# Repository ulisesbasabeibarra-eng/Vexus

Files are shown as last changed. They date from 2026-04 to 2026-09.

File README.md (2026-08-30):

# Triatlon-2026
Robot Triatlón para Bonaerenses 2026 por parte de los Alumnos de 6° año. **Campeones Región 2**

- [@Ulises Basabe](https://github.com/ulisesbasabeibarra-eng)
- [@Facundo Dominguez](https://github.com/facundodominguez1)
- [@Ramiro Trejo](https://github.com/RamiiTrejo)

## Componentes 

1-Esp32 38 pines

1-Bateria 2s de 450mAh

1-Bateria 3s de 1050mAh

2-Driver de motores BTS7960

2-Motores Titán de 1000RPM

## Sensores
1-Regleta **QTR8a** [Datasheet]()

3-Sensores infrarrojos **TCRT5000** [Datasheet]()

5-Sensores **Sharp Gp2y0a02yk0f**: [Datasheet]()

-3 frontales

-2 laterales

## PCB

Este PCB fue realizado con el software de diseño libre y gratuito KiCad, el cual nos facilita el uso debido a su interfaz intuitiva 

En este se implemento el diseño doble faz y componentes SMD (como lo son capacitores, una resitencia y un regulador)





## Modelo 3D

En este proyecto se utilizo Autodesk, plataforma de software, ademas de ser muy utilizado a la hora de hacer diseños 3D, gracias a que este ofrece una amplia gama de software como AutoCAD, Fusion 360, Inventor y 3ds Max, utilizados en sectores como la ingeniería, la arquitectura, el entretenimiento y el diseño de productos.

(https://postimg.cc/xcYmVDSj)

(https://postimg.cc/kB1QmJF6)

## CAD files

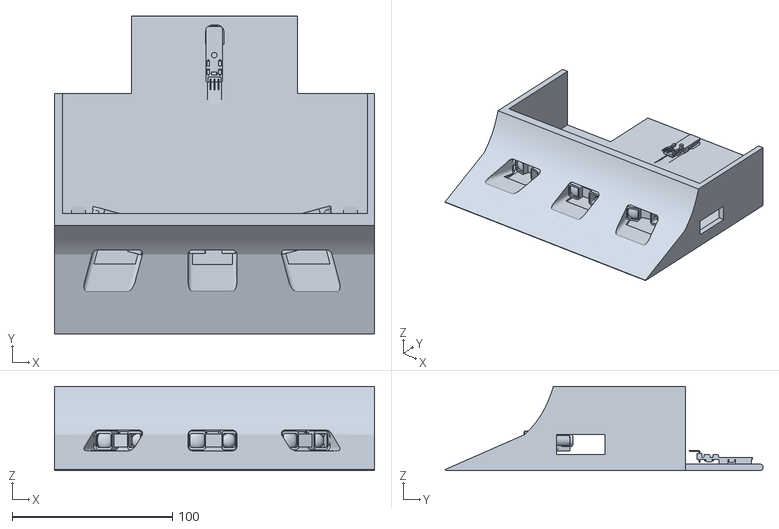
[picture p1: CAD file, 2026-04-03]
Carroceria/Vexus_V2/Revisión_1/Vexus V.2.stl
200.0 x 198.7 x 52.7

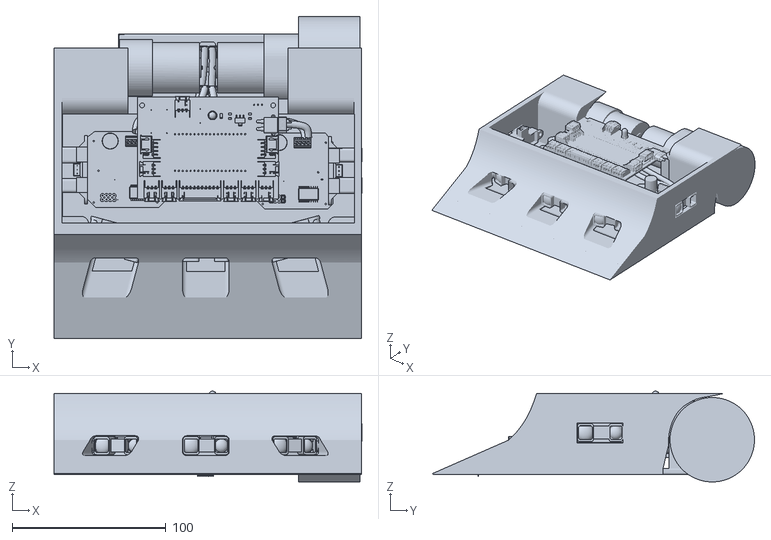
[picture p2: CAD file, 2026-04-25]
Carroceria/Vexus_V2/Revisión_2/Vexus v.3.stl
200.3 x 209.7 x 59.2

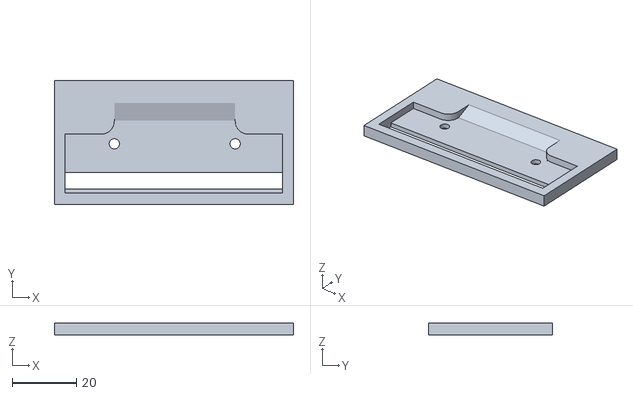
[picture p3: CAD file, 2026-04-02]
En desarrollo/Pruebas/Qtr (modelo regleta).stl
74.1 x 38.4 x 3.87

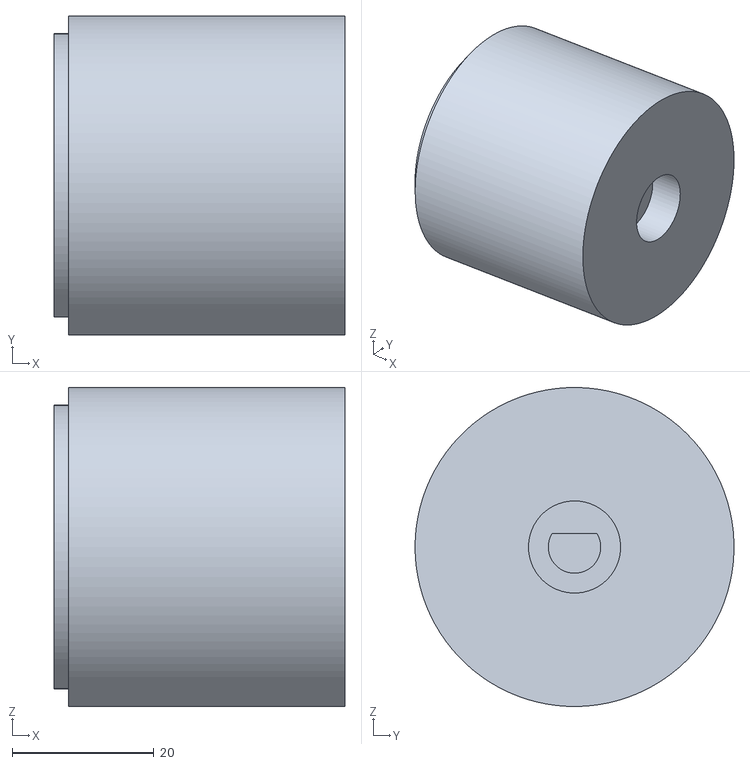
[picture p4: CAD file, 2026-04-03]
En desarrollo/Ruedas/Ruedas Vexus V.1.stl
41.0 x 45.0 x 45.0

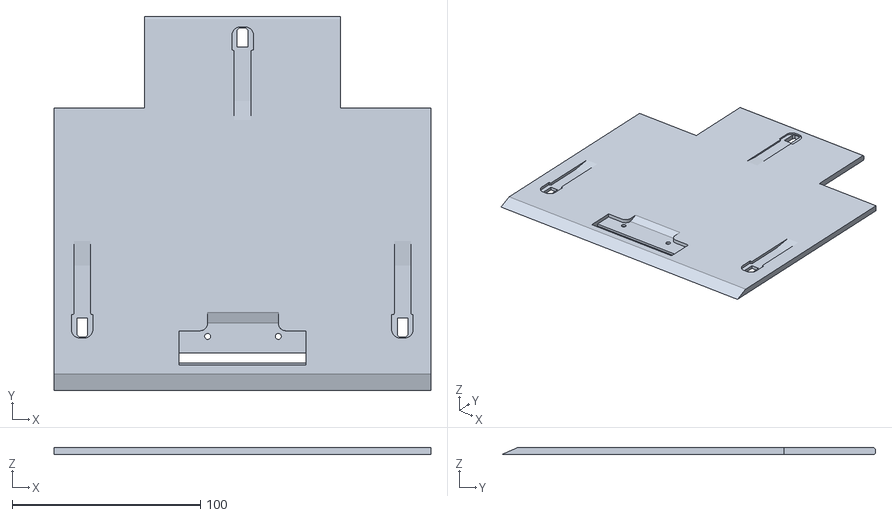
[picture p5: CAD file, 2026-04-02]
En desarrollo/Vexus.stl
200.0 x 198.5 x 3.87

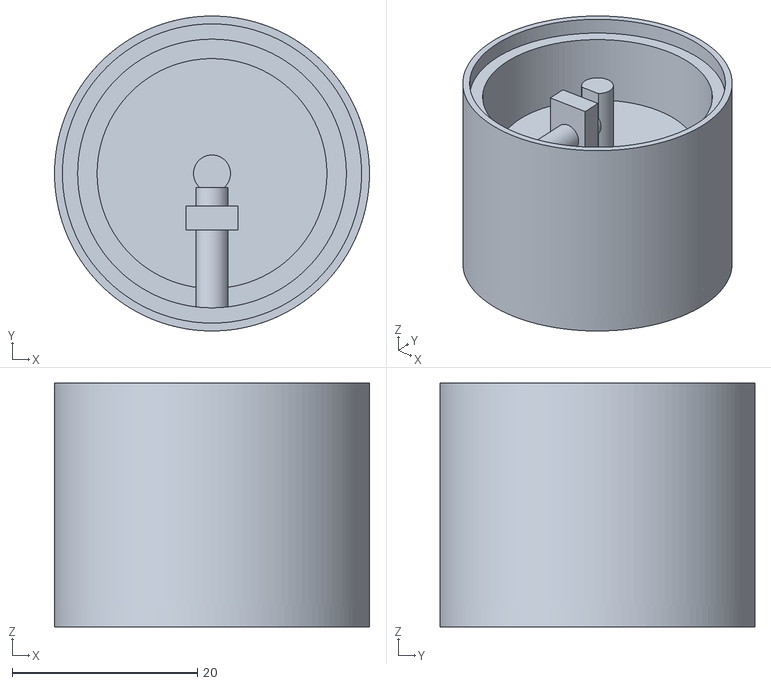
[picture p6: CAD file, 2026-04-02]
En desarrollo/Ruedas/Rueda_JGA.stl
34.0 x 34.0 x 26.3

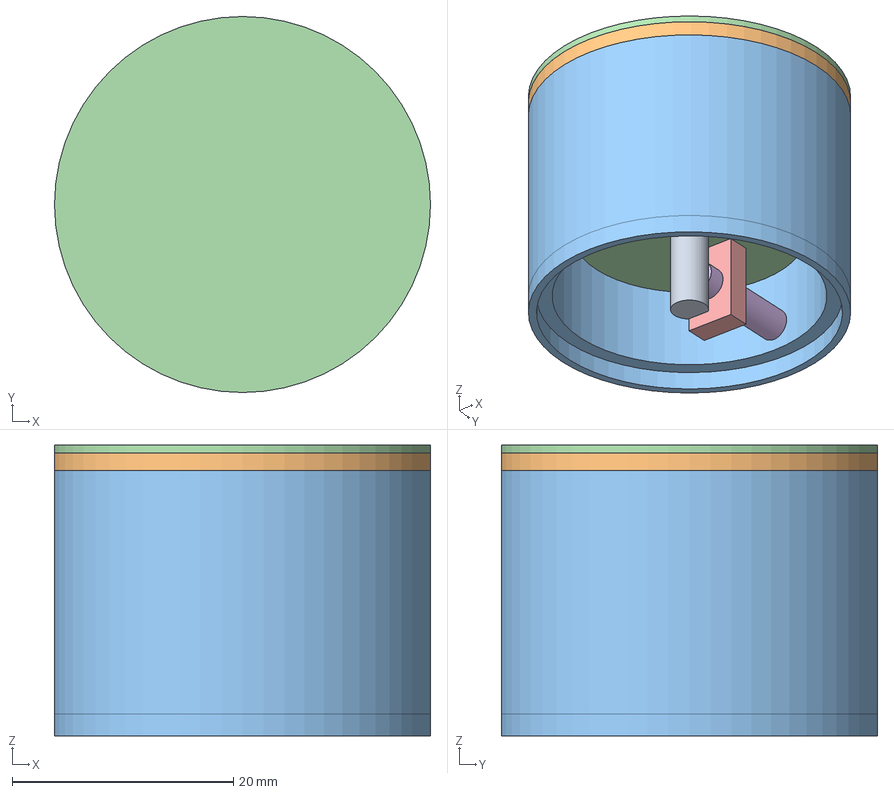
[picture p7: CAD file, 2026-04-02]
En desarrollo/Ruedas/Rueda_JGA25-370 v2.step
34.0 x 34.0 x 26.3 mm

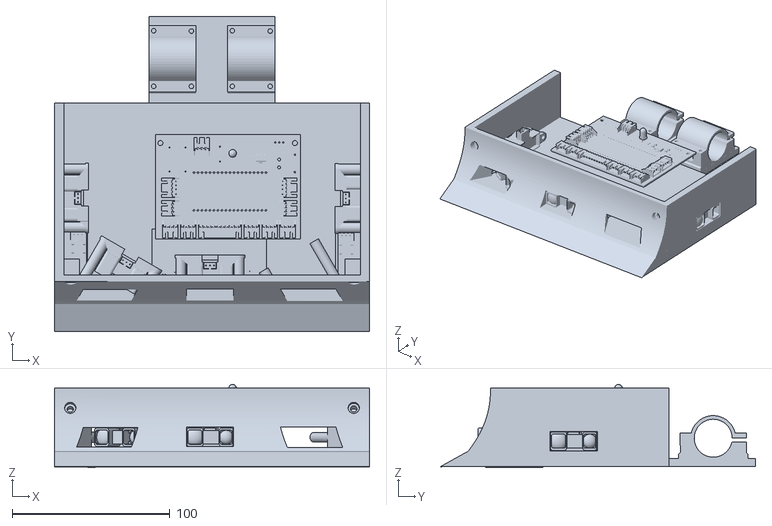
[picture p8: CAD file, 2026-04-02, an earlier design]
Carroceria/Vexus-V1/Vexus version 1.stl
200.0 x 200.0 x 52.9

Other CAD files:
Carroceria/Vexus-V1/Vexus V.1.f3z
Carroceria/Vexus_V2/Revisión_1/Vexus V.2.f3z
Carroceria/Vexus_V2/Revisión_2/Vexus v.3.f3z
En desarrollo/Ruedas/Ruedas Vexus V.1.f3d
En desarrollo/Vexus.f3z

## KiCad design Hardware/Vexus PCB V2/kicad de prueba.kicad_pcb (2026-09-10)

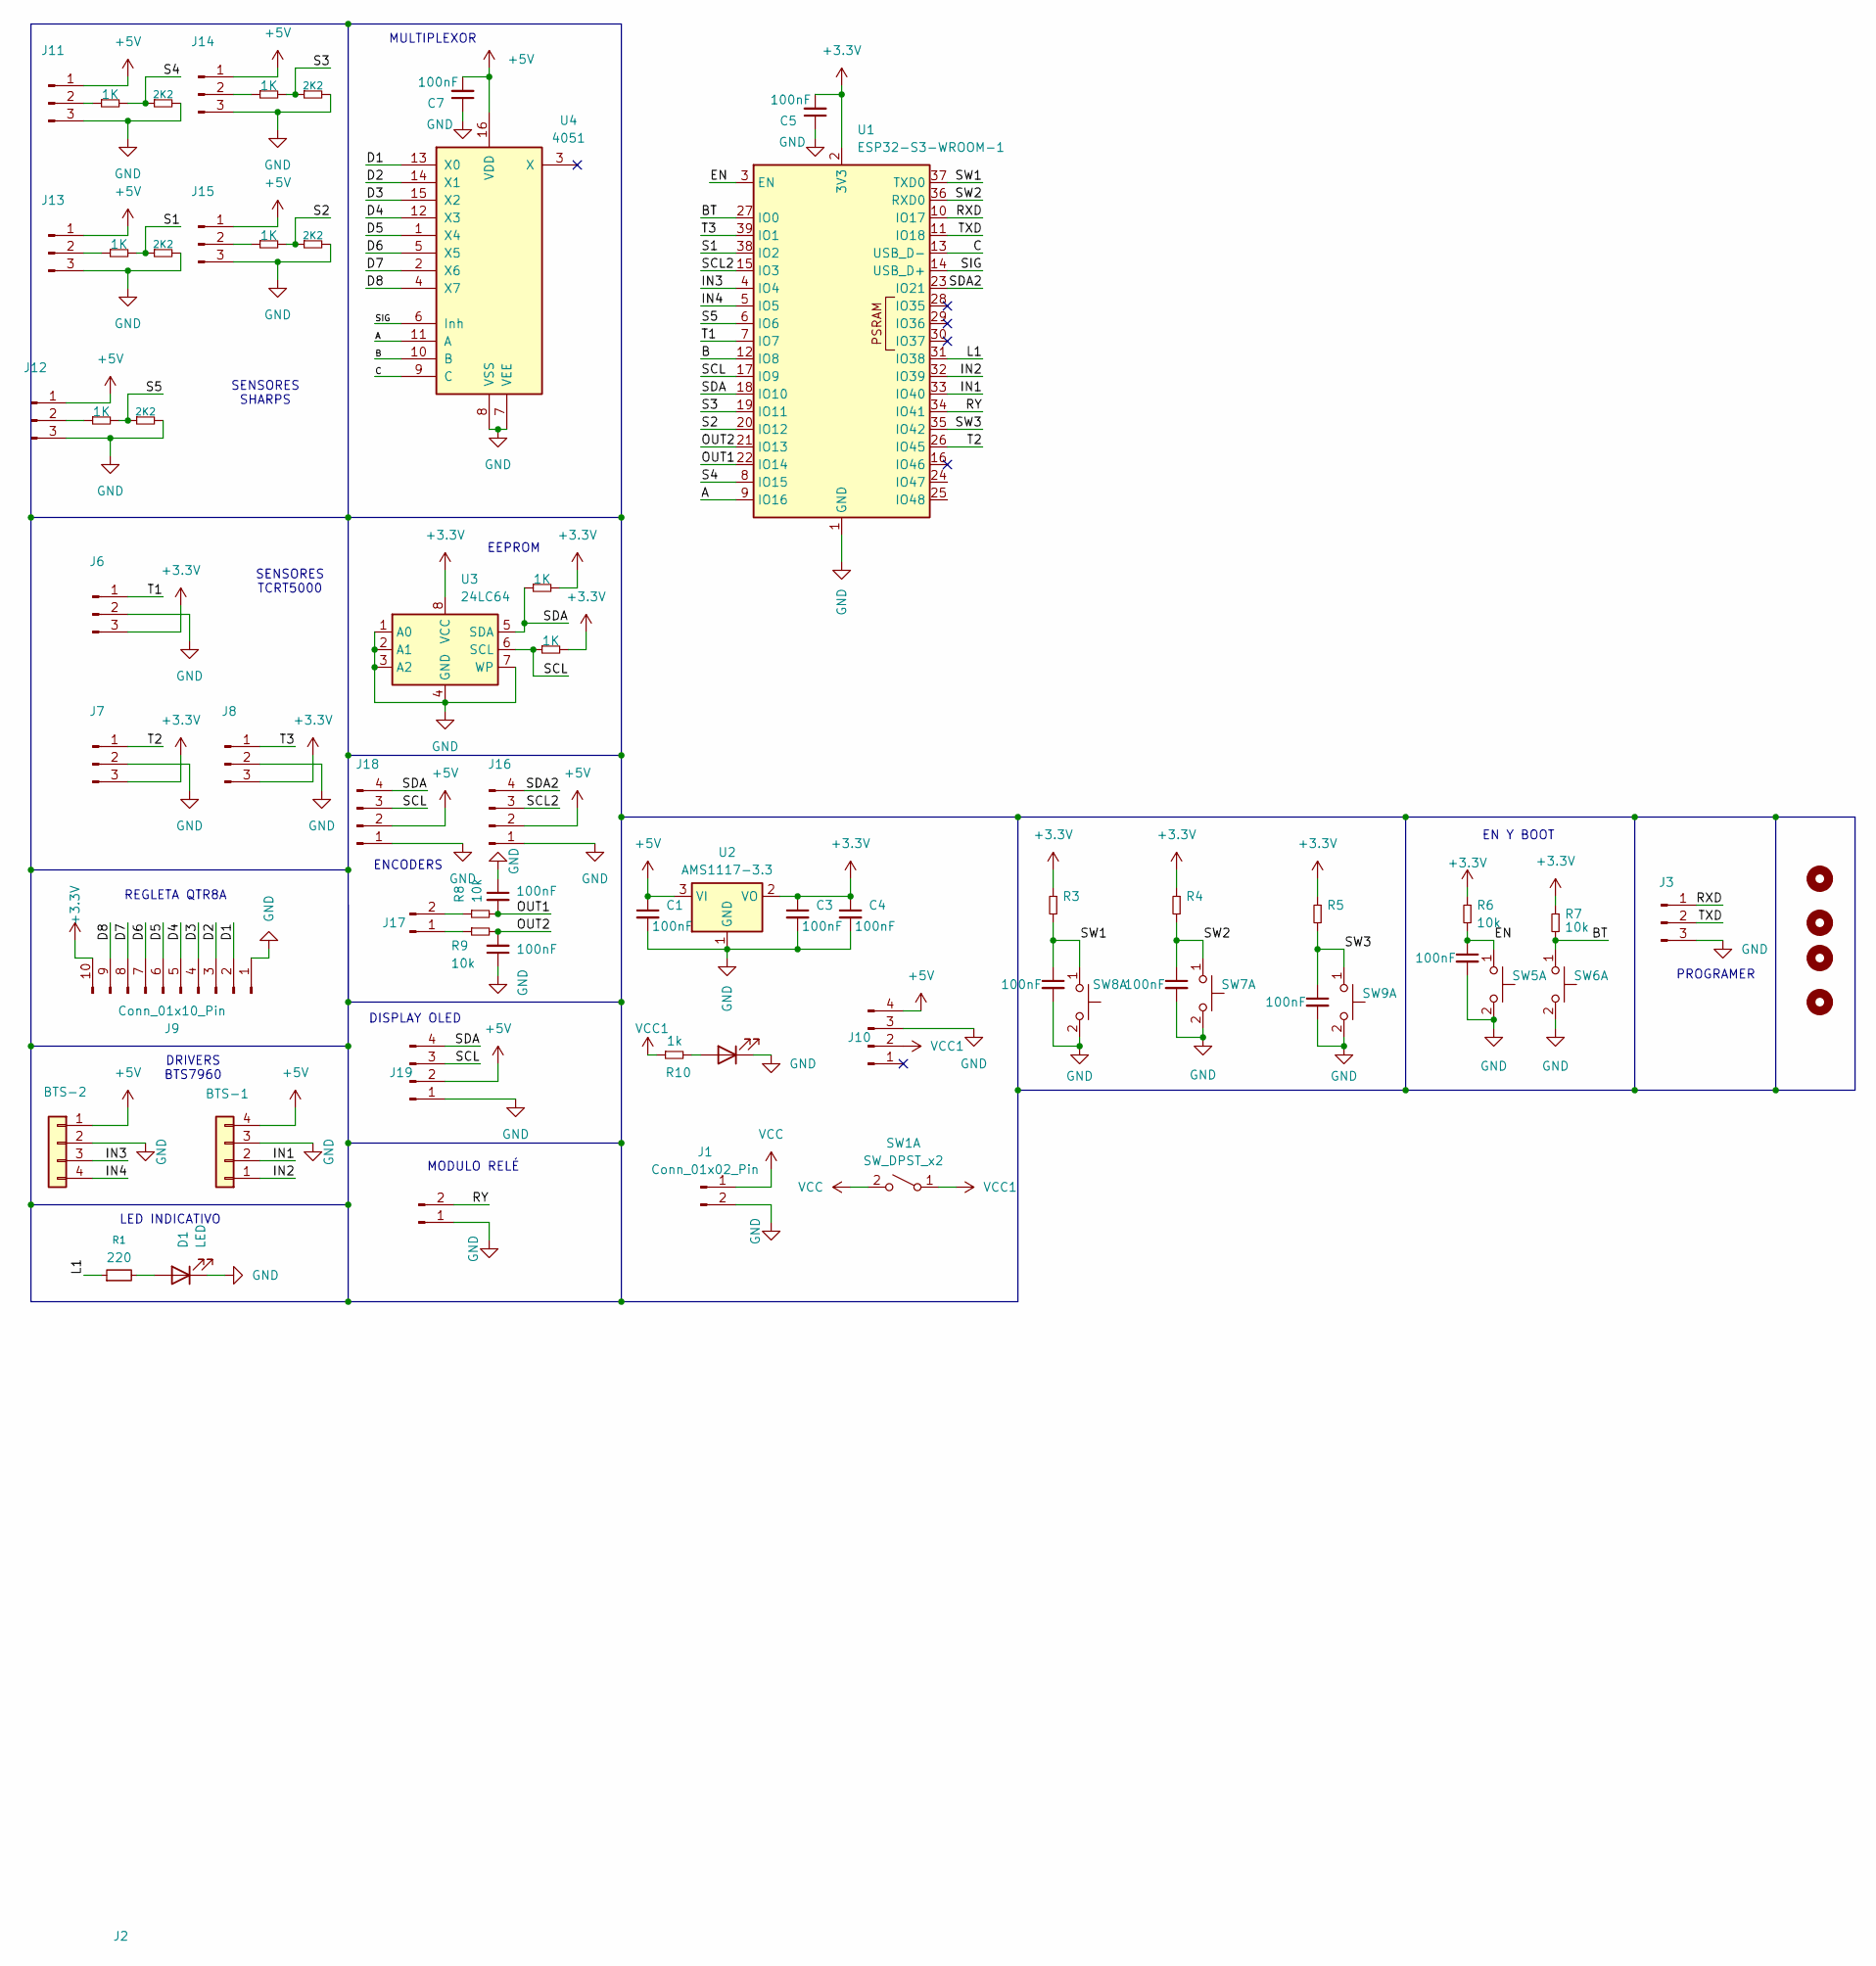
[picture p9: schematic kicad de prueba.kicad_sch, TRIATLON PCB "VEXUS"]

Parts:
C1, C3, C4, C5, C6, C7, C8, C9, C10, C11, C12: 100nF; C_0805_2012Metric_Pad1.18x1.45mm_HandSolder
D1, D2: LED; LED_0805_2012Metric_Pad1.15x1.40mm_HandSolder
H1, H2, H3, H4: MountingHole; MountingHole_3.2mm_M3_ISO7380
J1: Conn_01x02_Pin; AMASS_XT30PW-M_1x02_P2.50mm_Horizontal
J2: Conn_01x02_Pin; JST_XH_S2B-XH-A_1x02_P2.50mm_Horizontal
J3: Conn_01x03_Pin; PinHeader_1x03_P2.54mm_Vertical
J4: BTS-1; JST_XH_S4B-XH-A-1_1x04_P2.50mm_Horizontal
J5: BTS-2; JST_XH_S4B-XH-A-1_1x04_P2.50mm_Horizontal
J6, J7, J8, J11, J12, J13, J14, J15: Conn_01x03_Pin; JST_XH_S3B-XH-A-1_1x03_P2.50mm_Horizontal
J9: Conn_01x10_Pin; JST_XH_S10B-XH-A_1x10_P2.50mm_Horizontal
J10: Conn_01x04_Pin; Step_Down_Mini
J16, J18, J19: Conn_01x04_Pin; JST_XH_B4B-XH-A_1x04_P2.50mm_Vertical
J17: Conn_01x02_Pin; JST_XH_B2B-XH-A_1x02_P2.50mm_Vertical
R1: 220; R_0805_2012Metric_Pad1.20x1.40mm_HandSolder
R3, R4, R5, R6, R7, R8, R9: 10k; R_0805_2012Metric_Pad1.20x1.40mm_HandSolder
R10: 1k; R_0805_2012Metric_Pad1.20x1.40mm_HandSolder
R15, R16, R19, R21, R23, R25, R26: 1K; R_0805_2012Metric_Pad1.20x1.40mm_HandSolder
R17, R18, R20, R22, R24: 2K2; R_0805_2012Metric_Pad1.20x1.40mm_HandSolder
SW1: SW_DPST_x2; Switch Slide
SW5, SW6, SW7, SW8, SW9: SW_Push_Dual_x2; SW SMD 3.5X6X5
U1: ESP32-S3-WROOM-1
U2: AMS1117-3.3; SOT-223-3_TabPin2
U3: 24LC64; DIP-8_W7.62mm_LongPads
U4: 4051; SOIC-16_4.55x10.3mm_P1.27mm

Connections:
+3.3V: C3.1, C4.1, C5.2, J6.3, J7.3, J8.3, J9.10, R3.1, R4.1, R5.1, R6.1, R7.1, R25.2, R26.2, U1.2 (3V3), U2.2 (VO), U3.8 (VCC)
+5V: C1.1, C7.2, J4.4, J5.1, J10.4, J11.1, J12.1, J13.1, J14.1, J15.1, J16.2, J18.2, J19.2, U2.3 (VI), U4.16 (VDD)
/A: U1.9 (IO16), U4.11 (A)
/B: U1.12 (IO8), U4.10 (B)
/BT: R7.2, SW6.1 (C), U1.27 (IO0)
/C: U1.13 (USB_D-), U4.9 (C)
/D1: J9.2, U4.13 (X0)
/D2: J9.3, U4.14 (X1)
/D3: J9.4, U4.15 (X2)
/D4: J9.5, U4.12 (X3)
/D5: J9.6, U4.1 (X4)
/D6: J9.7, U4.5 (X5)
/D7: J9.8, U4.2 (X6)
/D8: J9.9, U4.4 (X7)
/EN: C6.1, R6.2, SW5.1 (C), U1.3 (EN)
/IN1: J4.2, U1.33 (IO40)
/IN2: J4.1, U1.32 (IO39)
/IN3: J5.3, U1.4 (IO4)
/IN4: J5.4, U1.5 (IO5)
/L1: R1.1, U1.31 (IO38)
/OUT1: C11.2, R8.2, U1.22 (IO14)
/OUT2: C12.2, R9.2, U1.21 (IO13)
/RXD: J3.1, U1.10 (IO17)
/RY: J2.2, U1.34 (IO41)
/S1: R23.2, R24.1, U1.38 (IO2)
/S2: R16.2, R18.1, U1.20 (IO12)
/S3: R19.2, R20.1, U1.19 (IO11)
/S4: R21.2, R22.1, U1.8 (IO15)
/S5: R15.2, R17.1, U1.6 (IO6)
/SCL: J18.3, J19.3, R26.1, U1.17 (IO9), U3.6 (SCL)
/SCL2: J16.3, U1.15 (IO3)
/SDA: J18.4, J19.4, R25.1, U1.18 (IO10), U3.5 (SDA)
/SDA2: J16.4, U1.23 (IO21)
/SIG: U1.14 (USB_D+), U4.6 (Inh)
/SW1: C10.1, R3.2, SW8.1 (C), U1.37 (TXD0)
/SW2: C9.1, R4.2, SW7.1 (C), U1.36 (RXD0)
/SW3: C8.1, R5.2, SW9.1 (C), U1.35 (IO42)
/T1: J6.1, U1.7 (IO7)
/T2: J7.1, U1.26 (IO45)
/T3: J8.1, U1.39 (IO1)
/TXD: J3.2, U1.11 (IO18)
GND: C1.2, C3.2, C4.2, C5.1, C6.2, C7.1, C8.2, C9.2, C10.2, C11.1, C12.1, D1.1 (K), D2.1 (K), J1.2, J2.1, J3.3, J4.3, J5.2, J6.2, J7.2, J8.2, J9.1, J10.3, J11.3, J12.3, J13.3, J14.3, J15.3, J16.1, J18.1, J19.1, R17.2, R18.2, R20.2, R22.2, R24.2, SW5.2 (D), SW6.2 (D), SW7.2 (D), SW8.2 (D), SW9.2 (D), U1.1 (GND), U1.40 (GND), U1.41 (GND), U2.1 (GND), U3.1 (A0), U3.2 (A1), U3.3 (A2), U3.4 (GND), U3.7 (WP), U4.7 (VEE), U4.8 (VSS)
unnamed: D1.2 (A), R1.2
unnamed: D2.2 (A), R10.2
unnamed: J11.2, R21.1
unnamed: J12.2, R15.1
unnamed: J13.2, R23.1
unnamed: J14.2, R19.1
unnamed: J15.2, R16.1
unnamed: J17.1, R9.1
unnamed: J17.2, R8.1
VCC: J1.1, SW1.2 (B)
VCC1: J10.2, R10.1, SW1.1 (A)

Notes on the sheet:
EEPROM
REGLETA QTR8A
SENSORES TCRT5000
DRIVERS BTS7960
LED INDICATIVO
PROGRAMER
SENSORES SHARPS
DISPLAY OLED
ENCODERS
MODULO RELÉ
MULTIPLEXOR
EN Y BOOT

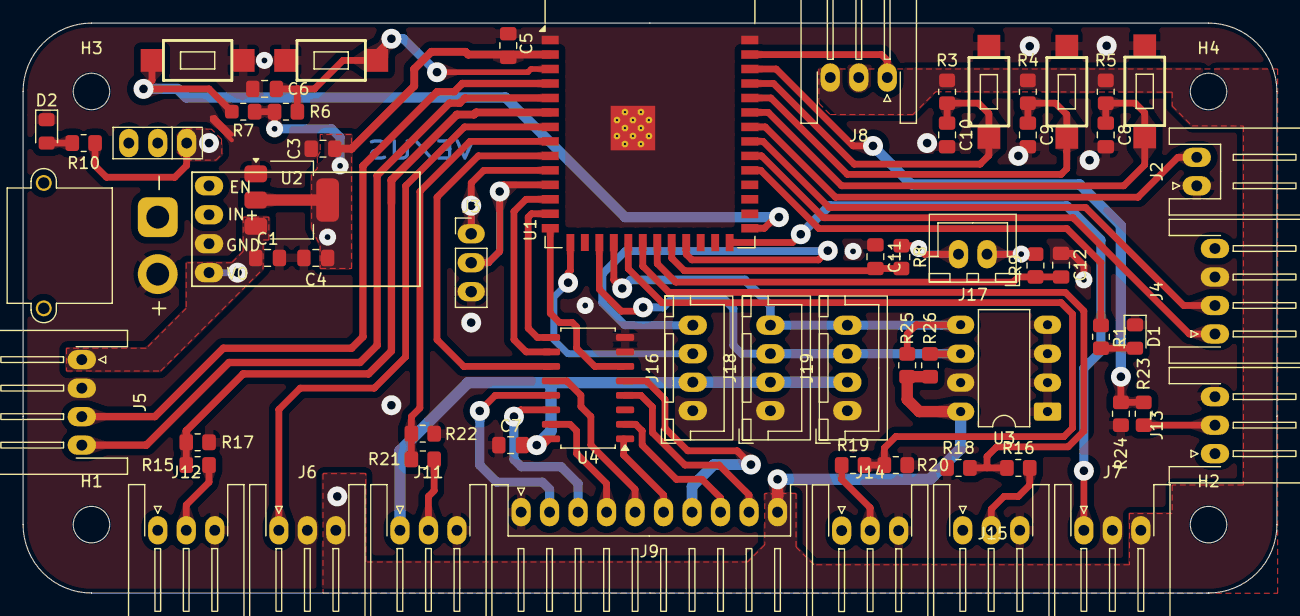
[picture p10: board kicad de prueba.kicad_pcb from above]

Board: 2 copper layers, 110.0 x 50.0 mm, 67 parts (0 on the bottom side), 53 nets.

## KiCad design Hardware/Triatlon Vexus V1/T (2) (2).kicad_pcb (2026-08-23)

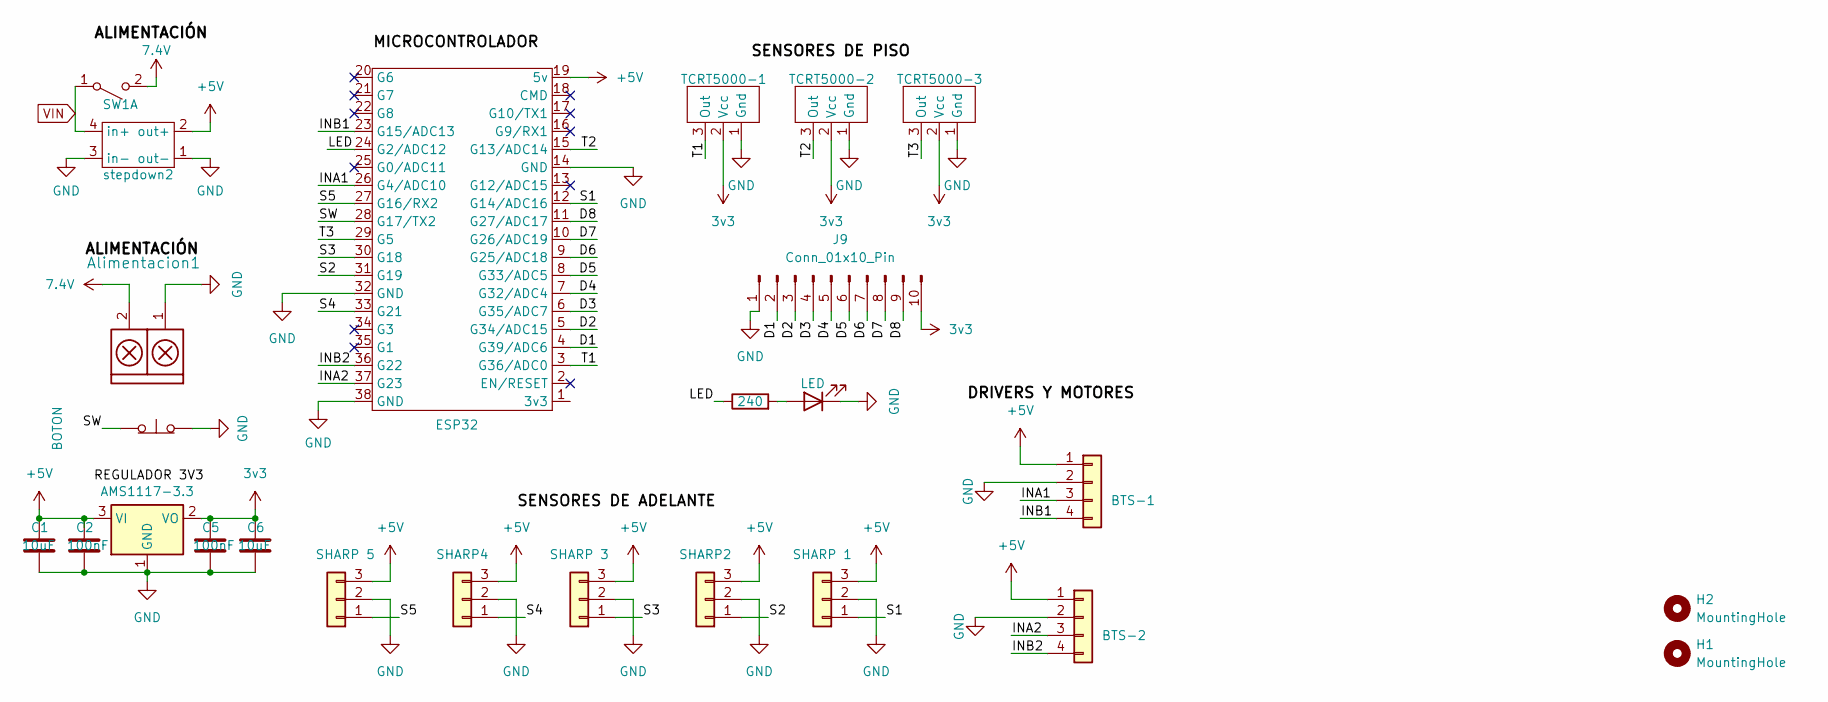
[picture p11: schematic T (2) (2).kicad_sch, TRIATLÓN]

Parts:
Alimentacion1: TB_1X2; AMASS_XT30PW-M_1x02_P2.50mm_Horizontal
C1, C6: 10uF; C_0805_2012Metric
C2, C5: 100nF; C_0805_2012Metric
D1: LED; LED_D5.0mm
ESP32: esp32 38 pin usb-c
H1, H2: MountingHole; MountingHole_3.2mm_M3_DIN965
J1: SHARP 1; JST_XH_S3B-XH-A-1_1x03_P2.50mm_Horizontal
J2: BTS-1; JST_XH_S4B-XH-A_1x04_P2.50mm_Horizontal
J3: SHARP2; JST_XH_S3B-XH-A-1_1x03_P2.50mm_Horizontal
J4: SHARP 3; JST_XH_S3B-XH-A-1_1x03_P2.50mm_Horizontal
J5: BTS-2; JST_XH_S4B-XH-A_1x04_P2.50mm_Horizontal
J7: SHARP 5; JST_XH_S3B-XH-A-1_1x03_P2.50mm_Horizontal
J8: SHARP4; JST_XH_S3B-XH-A-1_1x03_P2.50mm_Horizontal
J9: Conn_01x10_Pin; JST_XH_S10B-XH-A-1_1x10_P2.50mm_Horizontal
R1: 240; R_1206_3216Metric_Pad1.30x1.75mm_HandSolder
SW1: SW_DPST_x2; switch smd
SW2: BOTON; Button
TCRT5000-1, TCRT5000-2, TCRT5000-3: JST_XH_S3B-XH-A-1_1x03_P2.50mm_Horizontal
U2: AMS1117-3.3; SOT-223-3_TabPin2
stepdown2: STEPDOWN

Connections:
3v3: C5.1, C6.1, J9.10, TCRT5000-1.2 (Vcc), TCRT5000-2.2 (Vcc), TCRT5000-3.2 (Vcc), U2.2 (VO)
7.4V: Alimentacion1.2, SW1.2 (B)
+5V: C1.1, C2.1, ESP32.19 (5v), J1.3, J2.1, J3.3, J4.3, J5.1, J7.3, J8.3, U2.3 (VI), stepdown2.2 (out+)
/D1: ESP32.4 (G39/ADC6), J9.2
/D2: ESP32.5 (G34/ADC15), J9.3
/D3: ESP32.6 (G35/ADC7), J9.4
/D4: ESP32.7 (G32/ADC4), J9.5
/D5: ESP32.8 (G33/ADC5), J9.6
/D6: ESP32.9 (G25/ADC18), J9.7
/D7: ESP32.10 (G26/ADC19), J9.8
/D8: ESP32.11 (G27/ADC17), J9.9
/INA1: ESP32.26 (G4/ADC10), J2.3
/INA2: ESP32.37 (G23), J5.3
/INB1: ESP32.23 (G15/ADC13), J2.4
/INB2: ESP32.36 (G22), J5.4
/LED: ESP32.24 (G2/ADC12), R1.1
/S1: ESP32.12 (G14/ADC16), J1.1
/S2: ESP32.31 (G19), J3.1
/S3: ESP32.30 (G18), J4.1
/S4: ESP32.33 (G21), J8.1
/S5: ESP32.27 (G16/RX2), J7.1
/SW: ESP32.28 (G17/TX2), SW2.1 (A)
/T1: ESP32.3 (G36/ADC0), TCRT5000-1.3 (Out)
/T2: ESP32.15 (G13/ADC14), TCRT5000-2.3 (Out)
/T3: ESP32.29 (G5), TCRT5000-3.3 (Out)
GND: Alimentacion1.1, C1.2, C2.2, C5.2, C6.2, D1.1 (K), ESP32.14 (GND), ESP32.32 (GND), ESP32.38 (GND), J1.2, J2.2, J3.2, J4.2, J5.2, J7.2, J8.2, J9.1, SW2.2 (B), TCRT5000-1.1 (Gnd), TCRT5000-2.1 (Gnd), TCRT5000-3.1 (Gnd), U2.1 (GND), stepdown2.1 (out-), stepdown2.3 (in-)
unnamed: D1.2 (A), R1.2
VIN: SW1.1 (A), stepdown2.4 (in+)

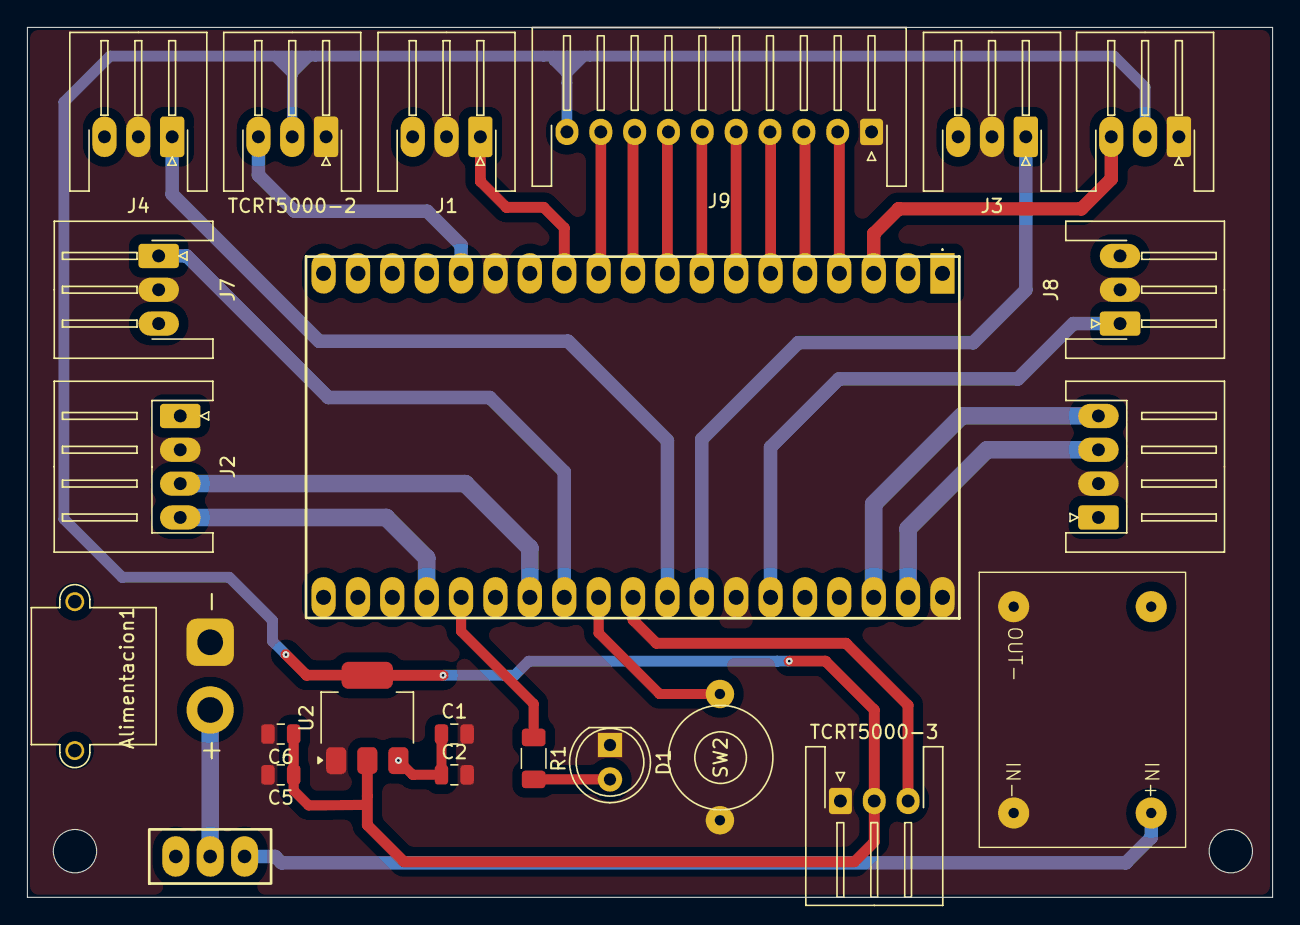
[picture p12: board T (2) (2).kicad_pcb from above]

Board: 2 copper layers, 92.0 x 64.3 mm, 25 parts (0 on the bottom side), 28 nets.

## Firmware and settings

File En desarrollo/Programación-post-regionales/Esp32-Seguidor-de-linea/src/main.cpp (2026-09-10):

#include <Arduino.h>
#include <Wire.h>
#include <Adafruit_GFX.h>
#include <Adafruit_SSD1306.h>

#include "Oled.h"
#include "Motores.h"
#include "Encoders.h"

Oled pantallita;
Motores motorcitos(4, 5, 40, 39);// IN1A, IN1B, IN2A, IN2B
Encoders myencoder;

#define boton1 43 //up - subir- derecha
#define boton2 44 //enter - calibrar 
#define boton3 42 //down - bajar - izquierda
#define led 38

#define TIME_PID 3

#define sig 3
#define pinA 16
#define pinB 19
#define pinC 20

#define eeprom_direccion 0x50

#define as5600_direccion 0x36

enum Estado {
  pantallazo,
  menu_principal,
  iniciar_carrera,
  comenzar, //es para que arranque el velocista
  calibracion,
  val_select,
  val_edit,
  EXTRA
};
Estado estadoActual = pantallazo;

// Variables de tiempo para Splash Screen
unsigned long tiempopantallazo = 0;

// Variables del Menú Principal
const int num_items = 6;
String menuItems[num_items] = {"Comenzar", "Calibracion", "Guardar Cal", "Cargar Cal", "Valores", "Extra"};
int menuIndex = 0;

// para el submenú de valores
int valorIndex = 0; 

// time cronómetro
unsigned long tiempoInicio = 0;
bool cronoActivo = false;

int Sensor[8] = {39,34,35,32,33,25,26,27}; // falta aclarar tema del multi

int umbrales[8] = {0,0,0,0,0,0,0,0};
bool estado_booleano[8] = {0,0,0,0,0,0,0,0};
uint8_t channel[8] = {4,5,6,7,8,9,10,11};

// === VARIABLES PID Y CONTROL ===
int pos = 0;
int poslast = 350;
float kp = 0.32; //aumenta la fuerza con la que el robot corrige el error, si se aumenta demasiado oscila
float ki = 0;
float kd = 6.45; //suavizante de la oscilación
float error = 0, error2 = 0, error3 = 0, error4 = 0, error5 = 0, error6 = 0;
float lastError = 0;
float integral = 0;
float derivative = 0;
float setpoint = 400;
int correccion = 0;
int max_rpm = 1000;
int baseSpeed = 370; //medido en rpm 5 de pwm en 255 equivale a 2 rpm aprox
bool anterior = 1; 

unsigned long lastTimePID = 0;

int PWM1 = baseSpeed;  //pwm de la izquierda
int PWM2 = baseSpeed;  //pwm de la derecha

int calcularPID(int lectura) {
    error = setpoint - lectura;
    integral = error + error2 + error3 + error4 + error5 + error6;
    derivative = error - lastError;
    lastError = error;
    
    error6 = error5;
    error5 = error4;
    error4 = error3;
    error3 = error2;
    error2 = error;
    
    return (kp * error + ki * integral + kd * derivative);
}
//------- ENCODERS -------
int calcularPWM(float rpmDeseada, float rpmReal, int pwmBase){
  float KP= 0.05;
  float Error = rpmDeseada - rpmReal;
  float Correccion = Error * KP;
  int pwmFinal = pwmBase + Correccion;

return constrain(pwmFinal, 0, 4095);
}
//-------MULTIPLEXOR-------

void leermulti2(){
  for(int i= 0; i<8; i++){
    digitalWrite(pinA, i&0x01);
    digitalWrite(pinB, i&0x02);
    digitalWrite(pinC, i&0x04);
    Sensor[i]=analogRead(sig);
  }
}

//-------FIN MULTIPLEXOR-------

void calibrar(){
    int blancos[8] = {0,0,0,0,0,0,0,0};
    int negro[8] = {0,0,0,0,0,0,0,0};
    digitalWrite(led, 1);
    while(digitalRead(boton2) == 1) { delay(1); }
    
    leermulti2();
    for (int x = 0; x < 8; x++) {
        blancos[x] = Sensor[x];    
    delay(100);
    }

    while(digitalRead(boton2) == 0) { delay(1); }
    digitalWrite(led, 0);
    delay(500);
    digitalWrite(led, 1);
    
    while(digitalRead(boton2)) { delay(1); }
    
    leermulti2();
    for (int x = 0; x < 8; x++) {
        negro[x] = Sensor[x];
    }
    for(int x = 0; x < 8; x++){
        umbrales[x] = (blancos[x] + negro[x]) / 2;
    }
    digitalWrite(led, 0);
    delay(1000);
    digitalWrite(led, 1);

    while(digitalRead(boton2) == 1) { delay(1); }
}

void sprint(){

  leermulti2();
  for(int x = 0; x < 8; x++){
    estado_booleano[x] =Sensor[x] > umbrales[x]? 0 : 1;
  }
  
  if(estado_booleano[0] == 0 && estado_booleano[0] != estado_booleano[7]){
    for(int x = 0; x < 8; x++){
      pos += 100 * estado_booleano[x];
    }
    anterior = 1;
  }
  if(estado_booleano[7] == 0 && estado_booleano[0] != estado_booleano[7]){
    for(int x = 0; x < 8; x++){
      pos += 100 * !estado_booleano[x];
    }
    anterior = 0;
  }
  if(estado_booleano[0] == estado_booleano[7]){
    if(anterior){
      for(int x = 0; x < 8; x++){
        pos += 100 * estado_booleano[x];
      }
    }
    else{
      for(int x = 0; x < 8; x++){
        pos += 100 * !estado_booleano[x];
      }
    }
  }
  
  if(micros() - lastTimePID >= TIME_PID){
      correccion = calcularPID(pos);
      lastTimePID = micros();
      
      int velocidadIzquierda = constrain (baseSpeed - correccion, 0, max_rpm);
      int velocidadDerecha  = constrain (baseSpeed + correccion, 0, max_rpm);

      int pwmBaseIzq = map(velocidadIzquierda, 0, max_rpm, 0, 4095);
      int pwmBaseDer = map(velocidadDerecha, 0, max_rpm, 0, 4095);

      float rpmRealIzq = myencoder.calculoRPM1();
      float rpmRealDer = myencoder.calculoRPM2();

      int pwmFinalIzquierda = calcularPWM(velocidadIzquierda, rpmRealIzq, pwmBaseIzq);
      int pwmFinalDerecha  = calcularPWM(velocidadDerecha, rpmRealDer, pwmBaseDer);

      motorcitos.moverMotores(pwmFinalIzquierda, pwmFinalDerecha);
  }

  pos = 0;
}

//-------OLED-------
void manejarValoresSelect(bool up, bool enter, bool down) {
  if (up) { 
    valorIndex--;
    if (valorIndex < 0) valorIndex = 3;
  }
  if (down) {
    valorIndex++;
    if (valorIndex > 3) valorIndex = 0;
  }
  if (enter) {
    if (valorIndex == 3) {
      estadoActual = menu_principal; 
    } else {
      estadoActual = val_edit;   //puede ir en vez de val_edit menu_principal
    }
  }
}

void ejecutarAccionMenu() {
  switch (menuIndex) {
      case 0: // Cronometro
      estadoActual = iniciar_carrera;
      break;
    case 1: // calibracion
      pantallita.mostrarMensaje("Calibrando...");
      calibrar();
      pantallita.mostrarMensaje("Calibracion OK");
      delay(1000);
      break;
    case 2: // guarda Calibracion
      pantallita.mostrarMensaje("Guardando...");
      {
        byte* datos = (byte*)umbrales; // Convertimos el arreglo de enteros a bytes
        for(unsigned int i = 0; i < sizeof(umbrales); i++) {
          Wire.beginTransmission(eeprom_direccion);
          Wire.write((i >> 8) & 0xFF);   // Parte alta de la dirección de memoria
          Wire.write(i & 0xFF);          // Parte baja de la dirección de memoria
          Wire.write(datos[i]);          // Dato a guardar
          Wire.endTransmission();
          delay(5); // Tiempo de escritura obligatorio del datasheet
        }
      }
      pantallita.mostrarMensaje("Cal Guardada!");
      delay(1500);
      break;
    case 3: // carga Calibracion
      pantallita.mostrarMensaje("Cargando...");
      {
        byte* datos = (byte*)umbrales;
        for(unsigned int i = 0; i < sizeof(umbrales); i++) {
          Wire.beginTransmission(eeprom_direccion);
          Wire.write((i >> 8) & 0xFF);
          Wire.write(i & 0xFF);
          Wire.endTransmission();
          
          Wire.requestFrom(eeprom_direccion, 1);
          if (Wire.available()) {
            datos[i] = Wire.read();
          }
        }
      }
      pantallita.mostrarMensaje("Datos Cargados!");
      delay(500);
      break;
    case 4: // Valores
      valorIndex = 0;
      estadoActual = val_select;
      break;
    case 5: // Extra
      estadoActual = EXTRA;
      break;
  }
}

void manejarMenuPrincipal(bool up, bool enter, bool down) {
  if (up) {
    menuIndex--;
    if (menuIndex < 0) menuIndex = num_items - 1;
  }
  if (down) {
    menuIndex++;
    if (menuIndex >= num_items) menuIndex = 0;
  }
  if (enter) {
  ejecutarAccionMenu();
  }
}

void manejarValoresEdit(bool up, bool enter, bool down) {
  if (enter) {
    estadoActual = val_select; 
    return;
  }
  if (valorIndex == 0) {
    if (up) baseSpeed += 100;
    if (down) baseSpeed -= 100;
  } 
  else if (valorIndex == 1) { 
    if (up) kp += 0.1;
    if (down) kp -= 0.1;
  } 
  else if (valorIndex == 2) { 
    if (up) kd += 0.5;
    if (down) kd -= 0.5;
  }
}

void dibujarMenuPrincipal() {
  pantallita.display.clearDisplay();
  pantallita.display.setTextSize(1);
  pantallita.display.setTextColor(WHITE);
  
  int inicio = max(0, menuIndex - 2);
  int fin = min(num_items, inicio + 4);
  
  for (int i = inicio; i < fin; i++) {
    int y = (i - inicio) * 16;
    if (i == menuIndex) {
      pantallita.display.setCursor(0, y);
      pantallita.display.print("> ");
      pantallita.display.print(menuItems[i]);
    } else {
      pantallita.display.setCursor(10, y);
      pantallita.display.print(menuItems[i]);
    }
  }
  pantallita.display.display();
}

void iniciarCuentaRegresiva() {
  for (int i = 5; i > 0; i--) {
    pantallita.display.clearDisplay();
    pantallita.display.setTextSize(3);
    pantallita.display.setCursor(50, 20);
    pantallita.display.print(i);
    pantallita.display.display();
    
    if (i <= 2){ 
    digitalWrite(led, HIGH); // Prende el LED en 2 y 1
    }
    else{ 
    digitalWrite(led, LOW);
    }
    delay(1000); // Espera 1 segundo
  }
  
  pantallita.display.clearDisplay();
  pantallita.display.setCursor(40, 20);
  pantallita.display.print("GO!");
  pantallita.display.display();
  
  digitalWrite(led, LOW);
  estadoActual = comenzar; // acá comienza
}

void dibujarValores() {
  pantallita.display.clearDisplay();
  pantallita.display.setTextSize(1);
  pantallita.display.setCursor(0, 0);
  
  if (estadoActual == val_select) {
    pantallita.display.print("Sel (Izq/Der)");
  } else {
    pantallita.display.print("Edit (Sub/Baj)");
  }

  pantallita.display.setCursor(0, 20);
  if (valorIndex == 0) pantallita.display.print(estadoActual == val_edit ? "[*" : "[ ");
  pantallita.display.print("Vel:"); pantallita.display.print(baseSpeed);
  if (valorIndex == 0) pantallita.display.print(estadoActual == val_edit ? "*]" : " ]");

  pantallita.display.setCursor(64, 20);
  if (valorIndex == 1) pantallita.display.print(estadoActual == val_edit ? "[*" : "[ ");
  pantallita.display.print("Kp:"); pantallita.display.print(kp, 1);
  if (valorIndex == 1) pantallita.display.print(estadoActual == val_edit ? "*]" : " ]");

  pantallita.display.setCursor(0, 40);
  if (valorIndex == 2) pantallita.display.print(estadoActual == val_edit ? "[*" : "[ ");
  pantallita.display.print("Kd:"); pantallita.display.print(kd, 1);
  if (valorIndex == 2) pantallita.display.print(estadoActual == val_edit ? "*]" : " ]");

  pantallita.display.setCursor(64, 40);
  if (valorIndex == 3) pantallita.display.print("[ ");
  pantallita.display.print("Volver");
  if (valorIndex == 3) pantallita.display.print(" ]");

  pantallita.display.display();
}

//-------FIN OLED MODIFICABLE-------

void setup() {
  Serial.begin(115200);
  pinMode(boton1, INPUT_PULLUP);
  pinMode(boton2, INPUT_PULLUP);
  pinMode(boton3, INPUT_PULLUP);
  pinMode(led, OUTPUT);

  digitalWrite(led, 0);

 //----Multiplexor----  
  pinMode(sig, INPUT);
  pinMode(pinA, OUTPUT);  
  pinMode(pinB, OUTPUT);
  pinMode(pinC, OUTPUT);  

  myencoder.begin();
  pantallita.begin();
/*  while(digitalRead(boton2)){}
  digitalWrite(led, LOW);
  delay(3000);
  digitalWrite(led, HIGH);
  delay(2000);
  digitalWrite(led, LOW);
*/  
}

void loop() {
  // Leemos botones (LOW es presionado)
  bool up = (digitalRead(boton1) == LOW);
  bool enter = (digitalRead(boton2) == LOW);
  bool down = (digitalRead(boton3) == LOW);

  if (up || enter || down) {
    delay(50);} // Debounce

  switch (estadoActual) {
    case pantallazo:
      // Verifica si pasaron 5 seg O si se presiona enter
      if ((millis() - tiempopantallazo >= 5000) || enter) {
        estadoActual = menu_principal;
        pantallita.display.clearDisplay();
      }
      break;

    case menu_principal:
      manejarMenuPrincipal(up, enter, down);
      dibujarMenuPrincipal();
      break;

      case iniciar_carrera:
      iniciarCuentaRegresiva();
      break;

      case comenzar:
      sprint(); 
      // frenar el robot si presiona --enter--
      if (enter) {
        motorcitos.moverMotores(0, 0);
        estadoActual = menu_principal;
        pantallita.mostrarMensaje("FRENADO");
        delay(500);
      }
      break;

    case val_select:
      manejarValoresSelect(up, enter, down);
      dibujarValores();
      break;

    case val_edit:
      manejarValoresEdit(up, enter, down);
      dibujarValores();
      break;

    case EXTRA:
      if (enter) estadoActual = menu_principal;
      pantallita.display.clearDisplay();
      pantallita.display.setCursor(10, 25);
      pantallita.display.setTextSize(2);
      pantallita.display.print("Rami gay");
      pantallita.display.setTextSize(1);
      pantallita.display.setCursor(10, 50);
      pantallita.display.print("Enter salir");
      pantallita.display.display();
      break;
  }

}

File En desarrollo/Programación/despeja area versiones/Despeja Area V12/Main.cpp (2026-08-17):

#include <Arduino.h>
#include <BluetoothSerial.h>

// pines para sharps
#define S1 39 // sensor der
#define S2 34 // sensor der 45
#define S3 25 // sensor del medio 
#define S4 26 // sensor izq 45
#define S5 27 // sensor izq

//pines para tcrt
#define T1 36 // tcrt de la derecha
#define T2 13 //tcrt de la izquierda
#define T3 5 // tcrt trasero

// ===== Motores ====
#define IN1A 22
#define IN1B 23 //bts 1 motor izquierdo
#define IN2A 4
#define IN2B 15 //bts 2 motor derecho

#define VMAX_DER 110
#define VBASE_DER 100
#define VMIN_DER 90

#define VMAX_IZQ 130
#define VBASE_IZQ 120
#define VMIN_IZQ 110

#define led 2
#define boton 17
#define DISTANCIA 1700 //para sensores - luego hacer pruebassss

unsigned long tiempo = 250;

unsigned long tiempo_inicio_ataque = 0;
unsigned long tiempo_deteccion_lateral = 0;
unsigned long tiempo_inicio_retroceso = 0;
unsigned long duracion_retorno = 0;

int mejor_lectura = 0; // guarda el valor ADC más alto (más cercano)
int lado_memorizado = 0;   // 0 = ninguno, 1 = izquierda, 2 = derecha

bool objetivo_memorizado = false;

// PWM's
int PWM1 = VBASE_IZQ;  //pwm de la izquierda
int PWM2 = VBASE_DER;  //pwm de la derecha

// Configuración de PWM para control de motores
const int frequency = 1000;
const int resolution = 8;

// Canales PWM del ESP32
const int ledChannel = 0;
const int ledChannel1 = 1;
const int ledChannel2 = 2;
const int ledChannel3 = 3;

// ===== INICIALIZACION DEL BLUETOOTH =====
BluetoothSerial SerialBT;

// ===== MODOS =====
enum MODOS{
    SALIR_ADE,
    ATACAR,
    BUSCAR,
    ATRAS,
    BUSCAR_IZ,
    BUSCAR_IZQ45,
    BUSCAR_DE,
    BUSCAR_DE45,
    RETROCEDER_MEMORIA
};
byte MODOS = BUSCAR;

float lectura(int pin){
  int suma = 0;
  for(int i = 0; i < 20; i++){
    suma += analogRead(pin);
  }
  return suma / 20;
}

void motores(int izq, int der) {

  izq = constrain(izq, -250, 250); //250 para no forzar el motor al maximo
  der = constrain(der, -250, 250); //250 para no forzar el motor al maximo   

  if (izq >= 0) {
    ledcWrite(ledChannel, izq);
    ledcWrite(ledChannel1, 0);
  } else {
    izq = izq * (-1);
    ledcWrite(ledChannel, 0);
    ledcWrite(ledChannel1, izq);
  }
  
  if (der >= 0) {
    ledcWrite(ledChannel2, der);
    ledcWrite(ledChannel3, 0);
  } else {
    der = der * (-1);
    ledcWrite(ledChannel2, 0);
    ledcWrite(ledChannel3, der);
  }
}

void salir() { 
    if (!digitalRead(T1)) { 
        unsigned long tiempo_inicio = millis(); 
        while (millis() < tiempo_inicio + 900) {
            motores(-VMAX_IZQ, -VMAX_DER);
        }
//        MODOS = BUSCAR_IZ; 
    }
    else if (!digitalRead(T2)) { 
        unsigned long tiempo_inicio = millis(); 
        while (millis() < tiempo_inicio + 900) {
            motores(-VMAX_IZQ, -VMAX_DER);
        }
        MODOS = BUSCAR_DE; 
    }
}

void salir_adelante(){
     if (!digitalRead(T3)) { 
        unsigned long tiempo_inicio = millis(); 
        while (millis() < tiempo_inicio + 900) {
            motores(VMAX_IZQ, VMAX_DER);
        }
        MODOS = BUSCAR; 
    }
}

void setup() {
    Serial.begin(115200);
    SerialBT.begin("vexus");
/* declaracion de pines sharp, unicamente se menciona por el funcionamiento del adc del esp
 for (int i = S1; i <= S5; i++){
    pinMode(i, INPUT);
 }
*/

  // declaracion de pines tcrt  
  pinMode(T1, INPUT);
  pinMode(T2, INPUT);
  pinMode(T3, INPUT);

  // declaracion de pines motores
  pinMode(IN1A, OUTPUT);
  pinMode(IN1B, OUTPUT);
  pinMode(IN2A, OUTPUT);
  pinMode(IN2B, OUTPUT);

  pinMode(led, OUTPUT);
  digitalWrite(led, 0);
  pinMode(boton, INPUT_PULLUP);

  // Configuración de PWM en cada canal y pin
  ledcSetup(ledChannel, frequency, resolution);
  ledcAttachPin(IN1A, ledChannel);

  ledcSetup(ledChannel1, frequency, resolution);
  ledcAttachPin(IN1B, ledChannel1);

  ledcSetup(ledChannel2, frequency, resolution);
  ledcAttachPin(IN2A, ledChannel2);

  ledcSetup(ledChannel3, frequency, resolution);
  ledcAttachPin(IN2B, ledChannel3);
  delay(100);

  motores(0,0);

while(digitalRead(boton)){}
  digitalWrite(led, LOW);
  delay (3000);
  digitalWrite(led, HIGH);
  delay (2000);
  digitalWrite(led, LOW);
}

void loop() {

   bool borde_der = !digitalRead(T1); // TRUE si detecta línea blanca
   bool borde_izq = !digitalRead(T2); // TRUE si detecta línea blanca
   bool borde_atra = !digitalRead(T3); //TRUE si detecta línea blanca

    if (lectura(S3) <= 2000){ // sensor del medio       
        MODOS = ATACAR;                                     
    }                                                          
     else if (lectura(S2) <= DISTANCIA){//sensor der 45
        MODOS = BUSCAR_DE45;
    }
     else if (lectura(S4) <= DISTANCIA){//sensor izq 45
        MODOS = BUSCAR_IZQ45;
    }
    else if (lectura(S1) <= DISTANCIA){ // sensor der       
        MODOS = BUSCAR_DE;                                    
    }                                                      
    else if (lectura(S5) <= DISTANCIA){ // sensor izq     
        MODOS = BUSCAR_IZ;                                
    }                                                         

    else {
        MODOS = BUSCAR;
    }

    if (borde_izq || borde_der){//tcrt izq y der
        MODOS = ATRAS;
        }
    else if (borde_atra){
        MODOS = SALIR_ADE;
        }

    SerialBT.print(MODOS);

    switch (MODOS){
    case BUSCAR:
        motores(VMIN_IZQ, VMAX_DER);

        break;

    case BUSCAR_DE:
        motores(VMAX_IZQ, VMIN_DER);

        break;

    case BUSCAR_DE45:
        motores(-VBASE_IZQ, VBASE_DER);

        break;
 
    case BUSCAR_IZ:
        motores(VMIN_IZQ, VMAX_DER);

        break;

    case BUSCAR_IZQ45:
        motores(VBASE_IZQ, -VBASE_IZQ);

        break;

    case ATACAR:
        motores(VMAX_IZQ, VMAX_DER);
        {
            int lectura_izq = lectura(S5); // Sensor izquierdo (90°)
            int lectura_der = lectura(S1); // Sensor derecho (90°)
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

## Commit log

2026-04-21 Refactor motor control and integrate QTR sensors
    Updated motor control logic and added QTR sensor integration.
2026-04-24 Organizacion de las versiones de vexus
    [Vexus V.1.f3z, Vexus V.2.f3z, Vexus V.2.stl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]
2026-05-02 Add new file 'a' in Velocista-without-QTRSensors
2026-05-02 src line follower-without-QTRSensors
    Removed QTRSensors library and related code. Updated PID constants and motor control logic.
2026-05-18 Enhance README with components and sensors details
    Added detailed components and sensors sections to the README.
2026-07-05 Add new file 'a' in Velocista-without QTRsensors V2
2026-07-16 Refactor main.cpp for improved sensor handling
2026-07-30 Refactor main.cpp for better motor and sensor management
    Refactor motor control logic and improve sensor handling.
2026-08-04 Redireccion de las versiones de despeja area
2026-08-04 Add main.cpp for robot control with sensors
2026-08-07 Add Main.cpp for motor control and Bluetooth setup
    Initial implementation of Arduino program for motor control and sensor integration.
2026-08-07 Actualización PID
    Updated PID parameters and improved button handling logic.
2026-08-10 Codigo que funciona
2026-08-15 codigo que no funciona correctamente
    [Main.cpp]
2026-08-17 Codigo que funciona 2
2026-08-18 Codigo que funciona (RC)
    Adjusted speed mapping for left and right motors based on R2 input.
2026-08-18 Posible opcion para el torneo
2026-08-19 Actualización PID
    Updated PID controller parameters and added button feedback functionality.
2026-08-24 Pwm 1023
2026-08-24 Refactor motor control and sensor logic
    Updated motor control and sensor reading logic. Adjusted PWM frequency and constraints for motor speed.
2026-08-24 Actualización de nuevos pines, libs y resolucion de motores a 12bits
2026-08-30 Update battery specifications in README.md
2026-09-01 Actualizacion y creacion de clases para motores y oled (ya implementada en cod.principal)
2026-09-10 Implementacion de encoders, previo a las pruebas
